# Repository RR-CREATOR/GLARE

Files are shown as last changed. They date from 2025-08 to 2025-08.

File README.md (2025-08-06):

# GLARE  
**Glasses Linked Augmented Reality Engine // By RR-CREATOR (rrop)**



---

## Table of Contents
- [GLARE](#glare)
  - [Intro](#intro)
  - [Why I made this](#why-i-made-this)
  - [PCB](#pcb)
    - [Power](#power)
    - [Main](#main)
    - [Full Board](#full-board)
  - [CAD](#cad)
    - [HUD](#hud)
    - [Camera](#camera)
    - [Frame](#frame)
    - [FULL CAD](#full-cad)
  - [BOM](#bom)

---

## GLARE

### Intro
GLARE is a Glasses Linked Augmented Reality Engine.  
It is basically a glasses attachment.  
It has a custom pcb, which you could place either inside the frame of glasses if you 3d print the frame, or attach it outside.  
It has a custom HUD made using birdbath optics and a 0.39" display, on one side, so you aren't too disconnected with reality, and a lot of the issues caused by cheap optics are resolved through seperate vision.  
It features an esp32-s3-wroom-n16r8 motherboard which, along with a phone(to be added after testing pcb), will get data from 2 mics, a camera, a gyro and gps and give an Augmented Reality experience through the HUD, for assitance in day to day life.

### Why I made this
I made this as I wanted to build something cool yet realistic, something I could carry around with me, and something which I could learn from building.  
I have always wanted my own smart glasses, and what better way to get them than building them yourself?  
I also wanted to get better at pcb design and thus I decided to work on this project and make a custom mainboard.

---

## PCB
It has a custom pcb which serves as its mainboard.

### Power
The pcb has proper power management, and is powered by two batteries in parallel connected to a voltage supervisor.

The pcb also has a micro usb b port which is used to charge the LiPo batteries and is also used for programming the esp 32 module on the board.

It also has a battery gauge, and a power on/off button, along with a low power isolation.

It also has a 5V boost and a 5V to 3.3V LDO to power esp and other peripherals.



### Main
The pcb also has connections for various peripherals, including 2 mics for stereo sound, a camera, a micro oled display, a gps and gyro.

It also has a usb to uart module to programme this esp 32.



### Full Board

**Fully Traced Board:**  


**3D Model of PCB:**  



> Ik the pcb looks lik a cheap cybertruck :3

---

## CAD

### HUD
So the CAD has a representation of the HUD, attached to a small piece, to attach it to the frame.  
(the pieces of the hud will be glued with optically clear glue)



### Camera
It also has a small holder where the camera will go. The holder has an extended piece using which it will be glued to the glasses.



### Frame
The right leg/handle of the glasses frame has a simple design, with its bottom looking like a battery.



The left leg/handle on the other hand is modelled around the shape of the pcb, and is hollow with a cover so that the pcb can be enclosed in it.  
Also, it bottom is hollow, and designed so that a battery can be placed inside it.






### FULL CAD





---

## BOM

<table>
    <tr>
        <td>Category</td>
        <td>Component</td>
        <td>Part Number / Source</td>
        <td>Price (USD)</td>
        <td>Quantity</td>
        <td>Notes</td>
    </tr>
    <tr>
        <td>Core</td>
        <td>ESP32-S3-WROOM-1U-N16R8</td>
        <td>https://lcsc.com/product-detail/WiFi-Modules_ESPRESSIF-ESP32-S3-WROOM-1U-N16R8_C3013946.html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</td>
        <td>5.66</td>
        <td>1</td>
        <td>Core chip with wifi and bt</td>
    </tr>
    <tr>
        <td>Antenna</td>
        <td>Ezurio 001-0014</td>
        <td>https://www.digikey.com/en/products/detail/ezurio/001-0014/4732758</td>
        <td>3.41</td>
        <td>1</td>
        <td>2.4GHz for core</td>
    </tr>
    <tr>
        <td>Mosfet</td>
        <td>PMZ350UPEYL</td>
        <td>https://lcsc.com/product-detail/MOSFETs_Nexperia-PMZ350UPEYL_C478207.html?s_z=n_PMZ350UPEYL</td>
        <td>0.43</td>
        <td>10</td>
        <td>For display power switch</td>
    </tr>
    <tr>
        <td>USB to UART</td>
        <td>CH9102F</td>
        <td>https://lcsc.com/product-detail/USB-Converters_WCH-CH9102F_C2858418.html?s_z=n_CH9102F</td>
        <td>1.33</td>
        <td>1</td>
        <td>For Programming</td>
    </tr>
    <tr>
        <td>I�S Microphone</td>
        <td>SPH0645LM4H-B-8</td>
        <td>https://lcsc.com/product-detail/MEMS-Microphones_Knowles-SPH0645LM4H-B-8_C19190864.html?s_z=n_SPH0645LM4H-B</td>
        <td>8</td>
        <td>2</td>
        <td>MEMS microphone</td>
    </tr>
    <tr>
        <td>Transistors</td>
        <td>2SC4617R</td>
        <td>https://lcsc.com/product-detail/Bipolar-BJT_CBI-2SC4617R_C2836080.html?s_z=n_2SC4617R%2520BR</td>
        <td>0.35</td>
        <td>20</td>
        <td>Programming</td>
    </tr>
    <tr>
        <td>RGB LEDs</td>
        <td>WS2812B 2020</td>
        <td>https://lcsc.com/product-detail/RGB-LEDs-Built-in-IC_Worldsemi-WS2812B-2020_C965555.html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</td>
        <td>0.41</td>
        <td>5</td>
        <td>For visual indication</td>
    </tr>
    <tr>
        <td>Micro USB B</td>
        <td>1050170001</td>
        <td>https://lcsc.com/product-detail/USB-Connectors_MOLEX-1050170001_C136000.html?s_z=n_C136000</td>
        <td>1.67</td>
        <td>1</td>
        <td>Charging LiPo</td>
    </tr>
    <tr>
        <td>Battery Charger</td>
        <td>AP5054HTCER</td>
        <td>https://lcsc.com/product-detail/Battery-Management_Wuxi-Chipown-Micro-electronics-AP5054HTCER_C2843820.html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</td>
        <td>0.15</td>
        <td>1</td>
        <td>Charging LiPo</td>
    </tr>
    <tr>
        <td>Low Voltage Detector</td>
        <td>XC61CC3002MR-G</td>
        <td>https://lcsc.com/product-detail/Supervisor-and-Reset-ICs_TOREX-XC61CC3002MR-G_C2456347.html?s_z=n_XC61CC3002MR</td>
        <td>0.92</td>
        <td>5</td>
        <td>Voltage Supervisor</td>
    </tr>
    <tr>
        <td>Battery Fuel Gauge</td>
        <td>MAX17048</td>
        <td>https://lcsc.com/product-detail/Battery-Management-ICs_Maxim-Integrated-MAX17048G-T10_C2682616.html</td>
        <td>4.16</td>
        <td>1</td>
        <td>Battery Percent</td>
    </tr>
    <tr>
        <td>Voltage Boost</td>
        <td>SY7088</td>
        <td>https://lcsc.com/product-detail/DC-DC-Converters_Silergy-SY7088DGC_C178240.html?s_z=n_SY7088</td>
        <td>1.52</td>
        <td>5</td>
        <td>Convert input to 5V</td>
    </tr>
    <tr>
        <td>LDO</td>
        <td>NCP167BMX330TBG</td>
        <td>https://lcsc.com/product-detail/Voltage-Regulators-Linear-Low-Drop-Out-LDO-Regulators_onsemi-NCP167BMX330TBG_C892227.html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</td>
        <td>0.44</td>
        <td>1</td>
        <td>Convert 5V to 3.3V</td>
    </tr>
    <tr>
        <td>Schottky Diode</td>
        <td>RB160M-30</td>
        <td>https://lcsc.com/product-detail/Schottky-Diodes_High-Diode-RB160M-30_C2937163.html?s_z=n_C2937163</td>
        <td>0.38</td>
        <td>5</td>
        <td>Prevent back current in battery bypass</td>
    </tr>
    <tr>
        <td>Camera Module</td>
        <td>0V5640 160 AF</td>
        <td>https://www.aliexpress.com/item/3256806547258124.html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</td>
        <td>12.75</td>
        <td>1</td>
        <td>5MP autofocus camera</td>
    </tr>
    <tr>
        <td>Gyro + Accelo + Magneto</td>
        <td>ICM-20948</td>
        <td>https://lcsc.com/search?q=ICM-20948&amp;s_z=n_ICM-20948</td>
        <td>4.68</td>
        <td>1</td>
        <td>6-axis IMU</td>
    </tr>
    <tr>
        <td>GPS Module</td>
        <td>L86-M33</td>
        <td>https://www.mouser.in/ProductDetail/Quectel/L86-M33?qs=GedFDFLaBXFvEvNOo6IDYg%3D%3D</td>
        <td>12.82</td>
        <td>1</td>
        <td>Low-power GPS module</td>
    </tr>
    <tr>
        <td>Micro Oled Display</td>
        <td>ET039XGM OLED display + HDMI driver board</td>
        <td>Alibaba (including shipping) </td>
        <td>103</td>
        <td>1</td>
        <td>For HUD</td>
    </tr>
    <tr>
        <td>Mosfet main battery</td>
        <td>YJQD30P02A</td>
        <td>https://lcsc.com/product-detail/MOSFETs_YANGJIE-YJQD30P02A_C919546.html?s_z=n_C919546</td>
        <td>1.36</td>
        <td>5</td>
        <td>Mosfet for high power switching</td>
    </tr>
    <tr>
        <td>Mosfet main battery</td>
        <td>PMZ290UNE2YL</td>
        <td>https://lcsc.com/product-detail/MOSFETs_Nexperia-PMZ290UNE2YL_C478155.html?s_z=n_C478155</td>
        <td>0.53</td>
        <td>10</td>
        <td>Mosfet for high power switching</td>
    </tr>
    <tr>
        <td>Resistor</td>
        <td>10k ohm</td>
        <td>https://lcsc.com/product-detail/Chip-Resistor-Surface-Mount_FOJAN-FRC0402J103-TS_C2906885.html?s_z=n_C2906885</td>
        <td>0.05</td>
        <td>100</td>
        <td>Resistor</td>
    </tr>
    <tr>
        <td>Resistor</td>
        <td>150ohm</td>
        <td>https://lcsc.com/product-detail/Chip-Resistor-Surface-Mount_FOJAN-FRC0402F1500TS_C2909321.html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</td>
        <td>0.05</td>
        <td>100</td>
        <td>Resistor</td>
    </tr>
    <tr>
        <td>Resistor</td>
        <td>100k ohm</td>
        <td>https://lcsc.com/product-detail/Chip-Resistor-Surface-Mount_YAGEO-RC0402JR-07100KL_C106234.html?s_z=n_C106234</td>
        <td>0.06</td>
        <td>100</td>
        <td>Resistor</td>
    </tr>
    <tr>
        <td>Resistor</td>
        <td>2k ohm</td>
        <td>https://lcsc.com/product-detail/Chip-Resistor-Surface-Mount_YAGEO-RC0402FR-072KL_C60488.html?s_z=n_C60488</td>
        <td>0.06</td>
        <td>100</td>
        <td>Resistor</td>
    </tr>
    <tr>
        <td>Resistor</td>
        <td>1M ohm</td>
        <td>https://lcsc.com/product-detail/Chip-Resistor-Surface-Mount_YAGEO-RC0402FR-071ML_C138033.html</td>
        <td>0.07</td>
        <td>100</td>
        <td>Resistor</td>
    </tr>
    <tr>
        <td>Resistor</td>
        <td>470k</td>
        <td>https://lcsc.com/product-detail/Chip-Resistor-Surface-Mount_YAGEO-AC0402JR-07470KL_C227380.html</td>
        <td>0.05</td>
        <td>100</td>
        <td>Resistor</td>
    </tr>
    <tr>
        <td>Resistor/Resettable Fuse</td>
        <td>1A</td>
        <td>https://lcsc.com/product-detail/Resettable-Fuses_JDTfuse-ASMD0805-100_C135331.html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</td>
        <td>0.44</td>
        <td>10</td>
        <td>Charging LiPo</td>
    </tr>
    <tr>
        <td>Resistor</td>
        <td>147k</td>
        <td>https://lcsc.com/product-detail/Chip-Resistor-Surface-Mount_YAGEO-AC0402FR-07147KL_C226785.html</td>
        <td>0.11</td>
        <td>100</td>
        <td>Resistor</td>
    </tr>
    <tr>
        <td>Switch</td>
        <td>SPST Tactile Switch</td>
        <td>https://lcsc.com/product-detail/Tactile-Switches_USAKRO-UK-B0249-SP25Y_C493280.html</td>
        <td>0.85</td>
        <td>5</td>
        <td>User button</td>
    </tr>
    <tr>
        <td>Switch</td>
        <td>Slide Switch</td>
        <td>https://lcsc.com/product-detail/Slide-Switches_Korean-Hroparts-Elec-K3-1270L-F1_C145858.html?s_z=n_C145858</td>
        <td>0.72</td>
        <td>5</td>
        <td>Power on/off</td>
    </tr>
    <tr>
        <td>LiPo battery</td>
        <td>500mAh, 3.7V</td>
        <td>https://robu.in/product/500mah-pcm-protected-micro-li-po-battery-2/</td>
        <td>6</td>
        <td>2</td>
        <td>For power</td>
    </tr>
    <tr>
        <td>Optical Clear Glue</td>
        <td>LOCA</td>
        <td>https://www.aliexpress.com/item/2255800983414695.html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.</td>
        <td>9</td>
        <td>1</td>
        <td>For optics arrangement</td>
    </tr>
    <tr>
        <td>Beam Splitter Cube</td>
        <td>10x10x10mm (including shipping) </td>
        <td>https://www.getuscart.com/beam-splitter-cube-optical-glass-dichroic-prism-ratio-5050-spectrome-sicence-3</td>
        <td></td>
        <td>22</td>
        <td>For optics arrangement</td>
    </tr>
    <tr>
        <td>Combiner</td>
        <td>22x20mm(including shipping)</td>
        <td>https://www.aliexpress.us/item/3256807745776887.html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</td>
        <td>17</td>
        <td>1</td>
        <td>For optics arrangement</td>
    </tr>
    <tr>
        <td>Capacitor</td>
        <td>1uF</td>
        <td>https://lcsc.com/product-detail/Multilayer-Ceramic-Capacitors-MLCC-SMD-SMT_Samsung-Electro-Mechanics-CL05A105KP5NNNC_C14445.html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</td>
        <td>0.17</td>
        <td>100</td>
        <td>Capacitor</td>
    </tr>
    <tr>
        <td>Capacitor</td>
        <td>100nF</td>
        <td>https://lcsc.com/product-detail/Multilayer-Ceramic-Capacitors-MLCC-SMD-SMT_FH-0402B104K160NT_C41851.html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</td>
        <td>0.1</td>
        <td>100</td>
        <td>Capacitor</td>
    </tr>
    <tr>
        <td>Capacitor</td>
        <td>200pF</td>
        <td>https://lcsc.com/product-detail/Multilayer-Ceramic-Capacitors-MLCC-SMD-SMT_YAGEO-CC0402KRX7R9BB201_C277481.html</td>
        <td>0.12</td>
        <td>100</td>
        <td>Capacitor</td>
    </tr>
    <tr>
        <td>Capacitor</td>
        <td>10uF</td>
        <td>https://lcsc.com/product-detail/Multilayer-Ceramic-Capacitors-MLCC-SMD-SMT_Samsung-Electro-Mechanics-CL05A106MQ5NUNC_C15525.html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</td>
        <td>0.06</td>
        <td>10</td>
        <td>Capacitor</td>
    </tr>
    <tr>
        <td>Capacitor</td>
        <td>22uF</td>
        <td>https://lcsc.com/product-detail/Multilayer-Ceramic-Capacitors-MLCC-SMD-SMT_Murata-Electronics-GRM155R60J226ME11D_C415703.html</td>
        <td>0.73</td>
        <td>20</td>
        <td>Capacitor</td>
    </tr>
    <tr>
        <td>LED</td>
        <td>Red</td>
        <td>https://lcsc.com/product-detail/LED-Indication-Discrete_EVERLIGHT-16-213SURC-S530-A3-TR8_C136765.html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</td>
        <td>0.31</td>
        <td>10</td>
        <td>For charging indication</td>
    </tr>
    <tr>
        <td>Inductor</td>
        <td>1.5uH</td>
        <td>https://lcsc.com/product-detail/power-inductors_prod-tech-pspmaa0402-1r5m-anp_C436514.html</td>
        <td>0.74</td>
        <td>5</td>
        <td>Inductor</td>
    </tr>
    <tr>
        <td>PCB</td>
        <td>PCBA</td>
        <td>JLC Estimate (26$ pcb + 16$ shipping, may be more as I havent completed the process)</td>
        <td>40</td>
        <td></td>
        <td></td>
    </tr>
    <tr>
        <td>LiPo battery voltage meter</td>
        <td>QP38</td>
        <td>https://www.amazon.in/Robodo-QP38-Battery-Voltage-Display/dp/B073Q2ZFKF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</td>
        <td>2.68</td>
        <td>1</td>
        <td>for testing lipo voltage</td>
    </tr>
    <tr>
        <td>LiPo battery charger</td>
        <td>Type C</td>
        <td>https://www.amazon.in/Converter-Overcharge-Over-Current-Protection-Module/dp/B0DNCRTZXD</td>
        <td>1.6</td>
        <td>1</td>
        <td>for charging lipo</td>
    </tr>
    <tr>
        <td>1.5m Cable</td>
        <td>USB C to Micro HDMI</td>
        <td>https://www.flipkart.com/microware-hdmi-cable-1-5-m-usb-3-1-type-c/p/itm928cffbd6b34a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</td>
        <td>9</td>
        <td>1</td>
        <td>For display to work, without this display wont work</td>
    </tr>
    <tr>
        <td></td>
        <td></td>
        <td></td>
        <td></td>
        <td></td>
        <td></td>
    </tr>
    <tr>
        <td></td>
        <td></td>
        <td>JUST TO BE ON THE SAFER SIDE, ADDING 20$ for pcba unexpected costs</td>
        <td>20</td>
        <td></td>
        <td></td>
    </tr>
    <tr>
        <td></td>
        <td></td>
        <td></td>
        <td></td>
        <td></td>
        <td></td>
    </tr>
    <tr>
        <td></td>
        <td></td>
        <td></td>
        <td></td>
        <td></td>
        <td></td>
    </tr>
    <tr>
        <td></td>
        <td></td>
        <td></td>
        <td></td>
        <td></td>
        <td></td>
    </tr>
    <tr>
        <td></td>
        <td></td>
        <td>Total Cost</td>
        <td>295.94</td>
        <td></td>
        <td></td>
    </tr>
</table>

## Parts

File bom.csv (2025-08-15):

Category | Component | Part Number / Source | Price (USD) | Quantity | Notes
Core | ESP32-S3-WROOM-1U-N16R8 | https://lcsc.com/product-detail/WiFi-Modules_ESPRESSIF-ESP32-S3-WROOM-1U-N16R8_C3013946.html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 | 5.66 | 1 | Core chip with wifi and bt
Antenna | Ezurio 001-0014 | https://www.digikey.com/en/products/detail/ezurio/001-0014/4732758 | 3.41 | 1 | 2.4GHz for core
Mosfet | PMZ350UPEYL | https://lcsc.com/product-detail/MOSFETs_Nexperia-PMZ350UPEYL_C478207.html?s_z=n_PMZ350UPEYL | 0.43 | 10 | For display power switch
USB to UART | CH9102F | https://lcsc.com/product-detail/USB-Converters_WCH-CH9102F_C2858418.html?s_z=n_CH9102F | 1.33 | 1 | For Programming
I²S Microphone | SPH0645LM4H-B-8 | https://lcsc.com/product-detail/MEMS-Microphones_Knowles-SPH0645LM4H-B-8_C19190864.html?s_z=n_SPH0645LM4H-B | 8 | 2 | MEMS microphone
Transistors | 2SC4617R | https://lcsc.com/product-detail/Bipolar-BJT_CBI-2SC4617R_C2836080.html?s_z=n_2SC4617R%2520BR | 0.35 | 20 | Programming
RGB LEDs | WS2812B 2020 | https://lcsc.com/product-detail/RGB-LEDs-Built-in-IC_Worldsemi-WS2812B-2020_C965555.html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 | 0.41 | 5 | For visual indication
Micro USB B | 1050170001 | https://lcsc.com/product-detail/USB-Connectors_MOLEX-1050170001_C136000.html?s_z=n_C136000 | 1.67 | 1 | Charging LiPo
Battery Charger | AP5054HTCER | https://lcsc.com/product-detail/Battery-Management_Wuxi-Chipown-Micro-electronics-AP5054HTCER_C2843820.html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 | 0.15 | 1 | Charging LiPo
Low Voltage Detector | XC61CC3002MR-G | https://lcsc.com/product-detail/Supervisor-and-Reset-ICs_TOREX-XC61CC3002MR-G_C2456347.html?s_z=n_XC61CC3002MR | 0.92 | 5 | Voltage Supervisor
Battery Fuel Gauge | MAX17048 | https://lcsc.com/product-detail/Battery-Management-ICs_Maxim-Integrated-MAX17048G-T10_C2682616.html | 4.16 | 1 | Battery Percent
Voltage Boost | SY7088 | https://lcsc.com/product-detail/DC-DC-Converters_Silergy-SY7088DGC_C178240.html?s_z=n_SY7088 | 1.52 | 5 | Convert input to 5V
LDO | NCP167BMX330TBG | https://lcsc.com/product-detail/Voltage-Regulators-Linear-Low-Drop-Out-LDO-Regulators_onsemi-NCP167BMX330TBG_C892227.html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 | 0.44 | 1 | Convert 5V to 3.3V
Schottky Diode | RB160M-30 | https://lcsc.com/product-detail/Schottky-Diodes_High-Diode-RB160M-30_C2937163.html?s_z=n_C2937163 | 0.38 | 5 | Prevent back current in battery bypass
Camera Module | 0V5640 160 AF | https://www.aliexpress.com/item/3256806547258124.html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 | 12.75 | 1 | 5MP autofocus camera
Gyro + Accelo + Magneto | ICM-20948 | https://lcsc.com/search?q=ICM-20948&s_z=n_ICM-20948 | 4.68 | 1 | 6-axis IMU
GPS Module | L86-M33 | https://www.mouser.in/ProductDetail/Quectel/L86-M33?qs=GedFDFLaBXFvEvNOo6IDYg%3D%3D | 12.82 | 1 | Low-power GPS module
Micro Oled Display | ET039XGM OLED display + HDMI driver board | Alibaba (including shipping) | 110 | 1 | For HUD
Mosfet main battery | YJQD30P02A | https://lcsc.com/product-detail/MOSFETs_YANGJIE-YJQD30P02A_C919546.html?s_z=n_C919546 | 1.36 | 5 | Mosfet for high power switching
Mosfet main battery | PMZ290UNE2YL | https://lcsc.com/product-detail/MOSFETs_Nexperia-PMZ290UNE2YL_C478155.html?s_z=n_C478155 | 0.53 | 10 | Mosfet for high power switching
Resistor | 10k ohm | https://lcsc.com/product-detail/Chip-Resistor-Surface-Mount_FOJAN-FRC0402J103-TS_C2906885.html?s_z=n_C2906885 | 0.05 | 100 | Resistor
Resistor | 150ohm | https://lcsc.com/product-detail/Chip-Resistor-Surface-Mount_FOJAN-FRC0402F1500TS_C2909321.html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 | 0.05 | 100 | Resistor
Resistor | 100k ohm | https://lcsc.com/product-detail/Chip-Resistor-Surface-Mount_YAGEO-RC0402JR-07100KL_C106234.html?s_z=n_C106234 | 0.06 | 100 | Resistor
Resistor | 2k ohm | https://lcsc.com/product-detail/Chip-Resistor-Surface-Mount_YAGEO-RC0402FR-072KL_C60488.html?s_z=n_C60488 | 0.06 | 100 | Resistor
Resistor | 1M ohm | https://lcsc.com/product-detail/Chip-Resistor-Surface-Mount_YAGEO-RC0402FR-071ML_C138033.html | 0.07 | 100 | Resistor
Resistor | 470k | https://lcsc.com/product-detail/Chip-Resistor-Surface-Mount_YAGEO-AC0402JR-07470KL_C227380.html | 0.05 | 100 | Resistor
Resistor/Resettable Fuse | 1A | https://lcsc.com/product-detail/Resettable-Fuses_JDTfuse-ASMD0805-100_C135331.html | 0.44 | 10 | Charging LiPo
Resistor | 147k | https://lcsc.com/product-detail/Chip-Resistor-Surface-Mount_YAGEO-AC0402FR-07147KL_C226785.html | 0.11 | 100 | Resistor
Switch | SPST Tactile Switch | https://lcsc.com/product-detail/Tactile-Switches_USAKRO-UK-B0249-SP25Y_C493280.html | 0.85 | 5 | User button
Switch | Slide Switch | https://lcsc.com/product-detail/Slide-Switches_Korean-Hroparts-Elec-K3-1270L-F1_C145858.html?s_z=n_C145858 | 0.72 | 5 | Power on/off
LiPo battery | 500mAh, 3.7V | https://robu.in/product/500mah-pcm-protected-micro-li-po-battery-2/ | 6 | 2 | For power
Optical Clear Glue | LOCA | https://www.aliexpress.com/item/2255800983414695.html?mp=1 | 9 | 1 | For optics arrangement
Beam Splitter Cube | 10x10x10mm (including shipping) | https://www.getuscart.com/beam-splitter-cube-optical-glass-dichroic-prism-ratio-5050-spectrome-sicence-3 | 22 | 1 | For optics arrangement
Combiner | 22x20mm (including shipping) | https://www.aliexpress.us/item/3256807745776887.html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 | 17 | 1 | For optics arrangement
Capacitor | 1uF | https://lcsc.com/product-detail/Multilayer-Ceramic-Capacitors-MLCC-SMD-SMT_Samsung-Electro-Mechanics-CL05A105KP5NNNC_C14445.html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 | 0.17 | 100 | Capacitor
Capacitor | 100nF | https://lcsc.com/product-detail/Multilayer-Ceramic-Capacitors-MLCC-SMD-SMT_FH-0402B104K160NT_C41851.html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 | 0.1 | 100 | Capacitor
Capacitor | 200pF | https://lcsc.com/product-detail/Multilayer-Ceramic-Capacitors-MLCC-SMD-SMT_YAGEO-CC0402KRX7R9BB201_C277481.html | 0.12 | 100 | Capacitor
Capacitor | 10uF | https://lcsc.com/product-detail/Multilayer-Ceramic-Capacitors-MLCC-SMD-SMT_Samsung-Electro-Mechanics-CL05A106MQ5NUNC_C15525.html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 | 0.06 | 10 | Capacitor
Capacitor | 22uF | https://lcsc.com/product-detail/Multilayer-Ceramic-Capacitors-MLCC-SMD-SMT_Murata-Electronics-GRM155R60J226ME11D_C415703.html | 0.73 | 20 | Capacitor
LED | Red | https://lcsc.com/product-detail/LED-Indication-Discrete_EVERLIGHT-16-213SURC-S530-A3-TR8_C136765.html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 | 0.31 | 10 | For charging indication
Inductor | 1.5uH | https://lcsc.com/product-detail/power-inductors_prod-tech-pspmaa0402-1r5m-anp_C436514.html | 0.74 | 5 | Inductor
PCB | PCBA | JLC Estimate (26$ pcb + 16$ shipping, may be more as I havent completed the process) | 40
LiPo battery voltage meter | QP38 | https://www.amazon.in/Robodo-QP38-Battery-Voltage-Display/dp/B073Q2ZFKF | 2.68 | 1 | for testing lipo voltage
LiPo battery charger | Type C | https://www.amazon.in/Converter-Overcharge-Over-Current-Protection-Module/dp/B0DNCRTZXD | 1.6 | 1 | for charging lipo
1.5m Cable | USB C to Micro HDMI | https://www.flipkart.com/microware-hdmi-cable-1-5-m-usb-3-1-type-c/p/itm928cffbd6b34a?pid=ACCF8DCB4FU6Z7SN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 | 9 | 1 | For display to work, without this display wont work
 |  | JUST TO BE ON THE SAFER SIDE, ADDING 20$ for pcba unexpected costs | 20
 |  | Total Cost | 302.94

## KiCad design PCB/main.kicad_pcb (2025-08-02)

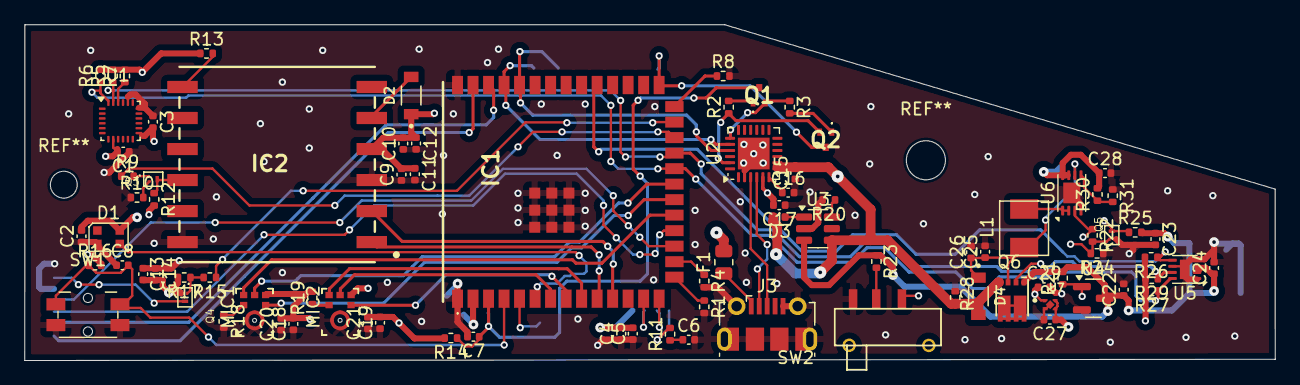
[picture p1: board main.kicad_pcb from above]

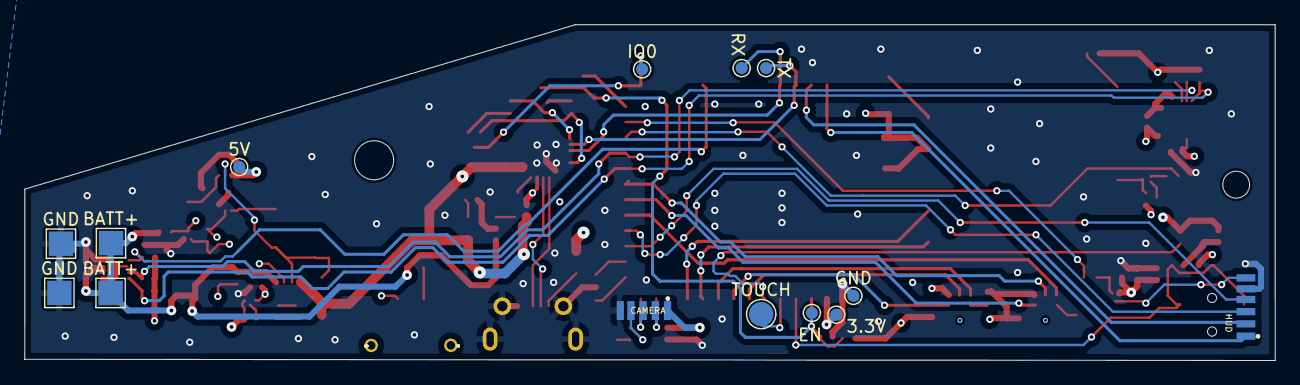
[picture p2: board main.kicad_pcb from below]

Board: 4 copper layers, 102.4 x 27.5 mm, 100 parts (14 on the bottom side), 64 nets.

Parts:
3.3V: 3V3; TestPoint_Pad_D1.0mm
5V: 5V; TestPoint_Pad_D1.0mm
BATT+: BATT1+; TestPoint_Pad_2.0x2.0mm
BATT+#2: BATT2+; TestPoint_Pad_2.0x2.0mm
C1, C3, C4, C6, C8, C9, C10, C14, C16, C17, C20, C21, C22, C24, C27: 100nF; C_0402_1005Metric
C2, C5, C7, C11, C12, C13, C15, C25, C29: 1uF; C_0402_1005Metric
C18, C19: 200pF; C_0402_1005Metric
C23, C26, C28: 22uF; C_0402_1005Metric
CAMERA: Camera; Solder-5P-Connector
D1: WS2812B-2020; LED_WS2812B-2020_PLCC4_2.0x2.0mm
D2, D4: RB160M-30; DIO_RB160M-30
D3: Red; D_0402_1005Metric
EN: EN; TestPoint_Pad_D1.0mm
F1: 1A; R_0805_2012Metric
GND: BATT1-; TestPoint_Pad_2.0x2.0mm
GND#2: GND; TestPoint_Pad_D1.0mm
GND#3: BATT2-; TestPoint_Pad_2.0x2.0mm
HUD: HUD; Solder-6P-Connector
IC1: ESP32-S3-WROOM-1U-N16R8; ESP32S3WROOM1UN16R8
IC2: L86-M33; L80-M39
IO0: IO0; TestPoint_Pad_D1.0mm
J3: USB_B_Micro; USB_Micro-B_Molex-105017-0001
L1: 1.5uH; 1.5uH_YXMAA0402-1R5M-ANP
MIC1, MIC2: SPH0645LM4H-B; SPH0645LM4H-B-2
Q1, Q2: 2SC4617-R-TP; 2SC4617RTP
Q3, Q4: PMZ350UPEYL; DFN100X60X40-3N
Q5: PMZ290UNE2YL; DFN100X60X40-3N
Q6: YJQD30P02A; EMF20B02V
R1, R2, R3, R4, R7, R8, R12, R13, R14, R15, R16, R18, R19, R23, R26: 10k; R_0402_1005Metric
R5, R6, R27, R29: 4.7k; R_0402_1005Metric
R9, R10: 1k; R_0402_1005Metric
R11, R25, R28: 1M; R_0402_1005Metric
R17, R21, R24: 100k; R_0402_1005Metric
R20: 2.1k; R_0402_1005Metric
R22: 150; R_0402_1005Metric
R30: 470k; R_0402_1005Metric
R31: 147k; R_0402_1005Metric
RX: RX; TestPoint_Pad_D1.0mm
SW1: SW_SPST; SMD_Switch_Panasonic_EVQPUL_EVQPUC_6.3x6.7
SW2: Power; SW_SMD_SPDT_Slide_9x6.9-hole
TOUCH: Touch Pad; TestPoint_Pad_D2.0mm
TX: TX; TestPoint_Pad_D1.0mm
U1: ICM-20948; InvenSense_QFN-24_3x3mm_P0.4mm
U2: CH9102F; QFN-24-1EP_4x4mm_P0.5mm_EP2.6x2.6mm
U3: AP5054HTC; SOT-23-6
U4: XC61CC3002MR; SOT-23
U5: MAX17048; DFN-8-1EP_2x2mm_P0.5mm_EP0.8x1.6mm
U6: SY7088; DFN-8-1EP_3x2mm_P0.5mm_EP1.7x1.4mm
U7: NCP167BMX330TBG; VREG_NCP167BMX330TBG

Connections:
+3.3V: 3.3V.1, C1.2, C3.2, C9.2, C10.2, C11.1, C12.1, C17.2, C18.2, C19.2, C20.2, C21.2, C29.1, D2.C, IC1.2 (3V3), IC2.4 (VCC), MIC1.5 (VDD), MIC2.5 (VDD), R5.2, R6.2, R7.2, R12.2, R13.1, R14.2, R16.2, R19.2, R26.2, R27.2, R29.2, U1.8 (VDDIO), U1.13 (VDD), U2.5 (VIO), U7.1 (OUT)
+5V: 5V.1, C2.2, C4.2, C5.2, C13.2, C14.2, C27.1, C28.1, CAMERA.1, D1.4 (VDD), Q4.2 (S), R17.2, R30.2, U6.7 (OUT), U6.8 (OUT), U7.3 (EN), U7.4 (IN)
ALRT: IC1.31 (IO38), R26.1, U5.5 (ALRT)
BATT+: BATT+.1, BATT+#2.1, C22.1, C23.1, C24.1, Q6.1 (S2), R21.2, R23.1, R25.2, U3.3 (BAT), U4.3 (VIN), U5.2 (CELL), U5.3 (Vdd)
BRT+: HUD.4, IC1.17 (IO9)
BRT-: HUD.3, IC1.18 (IO10)
D+: CAMERA.3, IC1.14 (IO20)
D-: CAMERA.2, IC1.13 (IO19)
DTR: Q2.2 (E), R2.1, U2.23 (~DTR)
EN: C7.1, EN.1, IC1.3 (EN), Q1.3 (C), R14.1
GND: C1.1, C2.1, C3.1, C4.1, C5.1, C6.2, C7.2, C8.1, C9.1, C10.1, C11.2, C12.2, C13.1, C14.1, C15.1, C16.2, C17.1, C18.1, C19.1, C20.1, C21.1, C22.2, C23.2, C24.2, C25.2, C26.2, C27.2, C28.2, C29.2, CAMERA.5, D1.2 (VSS), GND.1, GND#2.1, GND#3.1, HUD.5, IC1.1 (GND_1), IC1.40 (GND_2), IC1.41 (GND_3), IC1.42 (GND_4), IC1.43 (GND_5), IC1.44 (GND_6), IC1.45 (GND_7), IC1.46 (GND_8), IC1.47 (GND_9), IC1.48 (GND_10), IC1.49 (GND_11), IC2.3 (GND_1), IC2.12 (GND_2), J3.5 (GND), J3.6 (Shield), MIC1.3 (GND), MIC2.3 (GND), Q5.2 (S), R1.2, R4.2, R8.2, R10.1, R18.2, R20.2, R24.1, R28.1, R31.1, SW1.2 (B), SW2.1 (A), U1.18 (GND), U1.20 (GND), U2.2 (GND), U2.25 (GND), U3.2 (GND), U4.2 (GND/VSS), U5.1 (CTG), U5.4 (GND), U5.6 (QSTRT), U5.9 (EP), U6.4 (GND), U6.9 (Pad), U7.2 (GND), U7.5 (EPAD)
GRX: IC1.10 (IO17), IC2.1 (RXD1)
GTX: IC1.11 (IO18), IC2.2 (TXD1)
HUD+: HUD.6, Q4.3 (D)
HUD_EN: IC1.25 (IO48), R15.1
I2SCLK1: IC1.20 (IO12), MIC1.4 (BCLK)
I2SCLK2: IC1.8 (IO15), MIC2.4 (BCLK)
I2SDATA1: IC1.21 (IO13), MIC1.6 (DATA_OUT)
I2SDATA2: IC1.7 (IO7), MIC2.6 (DATA_OUT)
I2SWS1: IC1.19 (IO11), MIC1.1 (WS)
I2SWS2: IC1.9 (IO16), MIC2.1 (WS)
IO0: IC1.27 (IO0), IO0.1, Q2.3 (C)
unnamed: C6.1, R11.1
unnamed: D3.1 (K), U3.1 (~CHRG)
unnamed: IC1.15 (IO3), R1.1
unnamed: IC1.26 (IO45), R8.1
unnamed: IC1.16 (IO46), R4.1
unnamed: IC2.7 (FORCE_ON), R13.2
unnamed: IC2.10 (RESET), Q3.3 (D), R12.1
unnamed: D2.A, IC2.5 (V_BCKP)
unnamed: CAMERA.4, R11.2
unnamed: F1.1, J3.1 (VBUS)
unnamed: L1.2, U6.1 (LX), U6.2 (LX)
unnamed: MIC1.2 (SELECT), R18.1
unnamed: MIC2.2 (SELECT), R19.1
unnamed: Q1.1 (B), R2.2
unnamed: Q2.1 (B), R3.2
unnamed: Q3.1 (G), R9.2
unnamed: Q3.2 (S), R10.2
unnamed: Q4.1 (G), R15.2, R17.1
unnamed: Q5.3 (D), Q6.2 (G2), R25.1
unnamed: Q5.1 (G), R22.2, R24.2, SW2.2 (B)
unnamed: Q6.5 (D2), Q6.6 (D2), Q6.7 (D2), Q6.8 (D2)
unnamed: C25.1, C26.1, D4.C, L1.1, Q6.3 (S2), U6.6 (IN)
unnamed: R23.2, SW2.3 (C)
unnamed: R7.1, U1.22 (~CS)
unnamed: C16.1, U2.6 (V3)
unnamed: R20.1, U3.6 (PROG)
unnamed: R30.1, R31.2, U6.5 (FB)
PSEN: R21.1, R22.1, U4.1 (VOUT), U6.3 (EN)
RESETGPS: IC1.24 (IO47), R9.1
RGB: D1.3 (DIN), IC1.6 (IO6)
RTS: Q1.2 (E), R3.1, U2.19 (~RTS)
RX_ESP: IC1.36 (RXD0), RX.1, U2.21 (TXD)
RX_esp_hud: HUD.2, IC1.38 (IO2)
SCL: IC1.23 (IO21), R5.1, R29.1, U1.23 (SCL/SCLK), U5.7 (SCL)
SDA: IC1.22 (IO14), R6.1, R27.1, U1.24 (SDA/SDI), U5.8 (SDA)
Switch: C8.2, IC1.4 (IO4), R16.1, SW1.1 (A)
TX_ESP: IC1.37 (TXD0), TX.1, U2.20 (RXD)
TX_esp_hud: HUD.1, IC1.39 (IO1)
Touch: IC1.5 (IO5), TOUCH.1
USB+: J3.3 (D+), U2.3 (UD+)
USB-: J3.2 (D-), U2.4 (UD-)
VBUS: C15.2, D3.2 (A), D4.A, F1.2, Q6.4 (G2), R28.2, U2.7 (VDD5), U2.8 (VBUS), U3.4 (VCC)

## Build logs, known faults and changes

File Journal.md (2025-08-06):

---
Title: "GLARE"
Author: "rrop"
Description: "AR Glasses for everyday assistance"
Created On: "2025-07-25"
---

*Total Time Spent: 62h*

# July 25th: Optics Research
\
Ok so I googles AR glasses optics mechanisms and figured out that three main optics systems are used.\
smtg known as waveguide, smtg called birdbath and then the good old prism(also called wavesplitter optics by some websites).\
So basically for waveguide the have a projector like micro oled display which shoots light and the the guide it through inbuilt micro optics in the lens to get the hud. Buuuutttt :\
  1. super expensive
  2. Not hackable/Diy able
  3. No clue wehere i could even get it\
So waveguide is a no go. (ps its used in even realities G1)\
\
\
\
Then there is wavesplitter. So basically light from a micro oled is first collimated by a lens, and then passed through a special prism called beamsplitter, which makes it so that half the light entering the eye is from the display and other half from outside world.\
It works, and is pretty small, but the issue is it has a lot of imperfections and causes double images.\
I did an optics sim on phydemo for this



This is pretty simply optics so ill use either this or birdbath.

An example of birdbath is google glass explorer. It basically involves the same thing as the wabvesplitter, just tat light exiting prism is then focused by a semi transparent mirror onto the eye, along with a bit of light from outside world.\
This system reduces the imperfections by a lot, but is pretty bulky and tougher to get right.

Screenshot 2025-05-23 at 10 08 52 PM

SOOOO rn im super confused wut to do, i guess ill (as in make gpt ...) do some calc and figure out wut i want.\
OKKKKK, so i did some mth (:P) and figured out that i can try for a birdbath and if worst case it doesnt work i can just reposition the beam splitter prism and the system will work as wavesplitter optics. Yippe
So ill try to do birdbath ig.

**Session time spent: 5h**

# July 26th: More Research

So now tat I decided on birdbath, I had to find decide on the display I was gonna use. \
So, I did some searching about micro oleds and found a good one for a good price on alibaba.\
It also came with the driver board so that was a plus.\
Its the ET039XGM Micro OLED, and its 0.39".

SO now finally I could do some optics calcs.\
Before that, I also made a rough simulation of birdbath on phydemo.



here the outside light wiuld enter through the spherical mirror, which is supposed to be semi transparent [I cant show tht on phydemo :( ]\
\
So by estimation, using oled size, a 10x10x10mm beam splitter cube with a 45degree prism would suffice. \
Using this, and thin lens equation, i figured out tat the focal length of collimating lens shuld be 13-14mm, as thats distance bw display and prism. \
and then I can place the combiner just after the  prism. \
I also learned tat basically the combiner is almost flat, its slightly curevd. \
Its purpose is just to redirect light and include outside light. \
and as combiner is just after prism, its size has to be bigger than prism so it can effectively redirect light directed towards it. \
Sooo, ill be getting one of i guess a 20x20 size. \
I googles and yippe found a 22x20mm one. 

So basically i finally finished my optics, and will start my pcb tmrw.\
\
**Session time spent: 4h**

# July 27th: PCB Time, or is it?
\
Soo for the pcb, I decided that I would be making an FGPA board of sorts.\
So like basically a full on computer that could linux and that would control everything else.\
I decided I wanted a camera, google a bit and found that I liked the OV5640 AF. \
I also wanted a mic, gyro, gps and wifi nd bt capabilities. So I went on googling the components I could use.\
I decided upon the RK3566. Its one of the newer rockchip socs. Also i wanted it to be small, so instead of using an SOM I decided to use the SOC and choose the other stuf myself.\
For the RAM is choose IM8G32L4JCBG-046I which is a 1GB LPDDR4X. For flash, 128Mb of SPI NOR flash. Also a chip with 8gb emmc and for pmic an rk817-5.\
\
BOM img:
\

\
This research took lik 5 hrs, as I had to find the libraries, datasheets and kicad footprints and symbols of each as well.\
\
BUTT, As soon as I started on the schematic I realized smtg. THIS SHIT WAS WAYYYY TO COMPLEX. IT would take atleast 2 weeks and i dint hv tat much time :(\
SOO I scrapped this idea altogether and spent like another hour thinkin wut to do :/\
\
SOOOO..... I GIT A GOOD IDEA.\
Basically, ill use an esp 32 module as the core chip, and the peripherals will send data to it and stuf. Then itll communicate the data to a phone through its BT or wifi.\
The phone will do all the processing.\
ALSOOOOO, the hud driver board is HDMI. So i can directly control it through the phone through a usb c to micro hdmi cable. Another plus\
\
SO i made a rough plan of wut I would need.
1. esp
2. usb to uart to progrma it
3. 2 lipo bats for power (3.7v 500mah)
4. a voltage regulator
5. ldo
6. voltage boost
7. smtg to measure battery %
8. peripherals (stuf lik cam, gps, switches etc)
9. smtg to charge lipo

ANNDDD I DID A SHIT TON of research and finally decided upon a good esp32 module ill use as core.\
Its the ESP32-S3-WROOM-1U-N16R8\
It has 16GB flash, 8GB PSRAM wifi bt and usb support for my camera\
\
Ill do the rest of the bom tmrw\
\
**Session time spent: 7h**

# July 28th: BOM + Schematic
\
Soo for the pcb, I wont get into the details. Like there isnt much to discuss particularly.\
I just spent a shit ton of time (5 hrs) looking at datasheets, chat gpting and googling a lot of shit and finally finished the BOM.\ 
(it took a lot of time as I was also simultaneously finding the footprints and symbols of the parts I was gonna use)\
\

\
PS.. This diesbt have the otpics and lipo. Ill add those later.\
\
ANYWS. FINALLY TIME TO START WITH THE SCHEMATIC\
so i started with the power management part.\
\
So i was gonna have a micro usb b port which would be both for programming and charging the lipos.\
\

\
This was the schematic.\
So the usb prot d+ and d- ill later connect to d+ and d- of usb to uart.\
the fuse protect the charger from overcurrent.\
\
The prog sets charge current. For ap5054, its equal to 1200/resistance bw prog and gnd. as im using 2 lipos in parallel, ill keep it as 2k ohm so that the batteries charge at 600mAh.\
i.e. 0.6C which is good.\
\
Now time for the voltage supervisor to prevernt the lipos from burning out. : p\
\

\
here the vout will be connected to psen of the 5v boost to enable power saving.\
\
Now time for power on/off and the 5v boost.\
\

\
THIS SCHEMATIC TOOK WAYYYYYYY TOOOO LONG.\
\
now for the easy part. the battery gauge and the ldo to convert 5v to 3.3v(esp and lots of components have 3.3v logic)\
\

\
this was pretty easy.\
\
FINALLLYY, AFTER ALMOST THE ENTIRE DAY... THE POWER PART OF THE SCHEMATIC IS DONE\
\

\
**Session time spent: 13h**

# July 29th: Schematic 2
\
Time for the components part of the schematic\
\
USB TO UART: DONE\
\

\
Now i addes some transistors to the esp reset button and for the boot mode gpio. Ive connected them to the usb to uart dtr and rts.\
\

\
DONE\
\
Now the gyro:\
\

\
now the gps:\
\

\
Right I also added a gpio to control the state of the reset pin, so incase the gps misfires or gives wrong data, i can reset it through code.
\
Now the mics:\
\

\
Now the hud: for the hud also i added a gpio to control wether its on or off.\
\

\
The camera:\
\

\
the led:\
\

\
right i just remembered. I might have forgotten to mention this before, but i added a red led to the charging path, so that when the lipos are charging, you can visually tell\
\
and a touch reset user switch:\
\

\
and finally, after going through the datasheets a million times:\
the esp:\
\

\
There isnt much to say or explain about this, it was just adding and connecting the parts. But it still took me the entire day basically\
The schematic is officially done, and Ill start routing\
\
**Session time spent: 12h**

# July 30th: Routing
\
There isn't much to say abt this part. \
I just imported the parts from the schematic and spent a shit ton of time routing amd positioning everything.\
I started with the usb, i2s and i2c. Then the serial and uart, then the gpio and then power.\
The pwoer traces were pretty thick and others were default size pretty much.\
Its a 4 layer pcb so I can make it small and stuf.\
\
So basically I finished routing almost everything except the +5v, vbus and stuf. Will do tat tmrw\
\
**Session time spent: 12h**

# July 31th: Finishing Routing, CAD and Firmware
\
Ok so I spent lik 2 hrs and finished the routing.\
\

\
\
Now time for cad
\
For this I spent like 15 mins and found a step model of glasses.\ 
I imported that into my cad.\
Then i deleted their arms, extended two rectangles and modeled the base part slightly angles downwards and in the shape of battery so they can act as battery housing.\
I then modelled the left arm to be hollow and in such a way that my pcb sits firmly withing it, by creating a sketch around the pcb.\
I also modeled the hud after this, and a mount for the camera, with an extension where i can super glue it to the glasses.\
\
Overall, this entire modelling took me abt 4 hrs.\
\



Now time for the firmware.\
For the firmware, I decided to use platformio, so tat later on interfacing would be easier and testing and dev would also be pretty easy.\
\
SOOO, I created projected and luckily found a board verryy close to mine. The only diff was tat mine has 16Mb flash while this board has 8Mb.\
But i dont think while programming it would make much difference.\
\
Anyws, I organised stuf into folders. Figured out how platformio works a little more (2nd time using it)\
and wrote up basic code for all the components.\
\
So i googled and figured out that its better to add stuf in a folder called include so tat those files dont get called multiple times\
(I hv no clue wut this means, just tat multiple people online suggested it so ill do it : P )\
\
Anyws, finalllYY FIRMWARE DONE AND EVERYTHING DONE.... FOR now.. YIPPEEEEE : )\
\
**Session time spent: 10h**

**Total Time Spent: 62h**

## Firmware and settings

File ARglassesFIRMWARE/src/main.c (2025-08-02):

#include "utils/brightness.h"
#include "utils/microphones.h"
#include "utils/gps.h"
#include "utils/i2c_devices.h"
#include "display/hud.h"
#include "driver/gpio.h"
#include "driver/uart.h"

#define HUD_ENABLE_GPIO 48
#define HUD_UART_TX 1
#define HUD_UART_RX 2

void app_main(void) {
    gpio_reset_pin(HUD_ENABLE_GPIO);
    gpio_set_direction(HUD_ENABLE_GPIO, GPIO_MODE_OUTPUT);
    gpio_set_level(HUD_ENABLE_GPIO, 1);

    brightness_init();
    microphones_init();
    gps_init();
    i2c_devices_init();
}

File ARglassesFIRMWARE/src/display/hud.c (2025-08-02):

#include "display/hud.h"
#include "driver/uart.h"
#include "driver/gpio.h"

#define HUD_ENABLE_GPIO 48
#define HUD_UART_TX 1
#define HUD_UART_RX 2

void hud_init(void) {
    gpio_reset_pin(HUD_ENABLE_GPIO);
    gpio_set_direction(HUD_ENABLE_GPIO, GPIO_MODE_OUTPUT);
    gpio_set_level(HUD_ENABLE_GPIO, 1);

    uart_config_t uart_config = {
        .baud_rate = 115200,
        .data_bits = UART_DATA_8_BITS,
        .parity    = UART_PARITY_DISABLE,
        .stop_bits = UART_STOP_BITS_1,
        .flow_ctrl = UART_HW_FLOWCTRL_DISABLE
    };
    uart_driver_install(UART_NUM_2, 1024, 0, 0, NULL, 0);
    uart_param_config(UART_NUM_2, &uart_config);
    uart_set_pin(UART_NUM_2, HUD_UART_TX, HUD_UART_RX, UART_PIN_NO_CHANGE, UART_PIN_NO_CHANGE);
}

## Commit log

2025-08-02 Rename Frame with electronics and hud v2.step to CAD/Frame with electronics and hud v2.step
    [Frame with electronics and hud v2.step]
2026-06-29 Complete ESP32-S3 firmware with live transcription
    Fix I2S mic init (wrong clock, wrong slot width for SPH0645, never enabled)
    Add microphones_read() for actual PCM capture
    Add WiFi + WebSocket streaming pipeline (glare_net.c)
    Add HUD text output (hud_show/hud_show_n over UART)
    Wire app_main with NVS init and full boot sequence
    Add glare_config.h for WiFi/WS/audio config
    Add reference transcription backend (faster-whisper)
    Add board JSON, sdkconfig.defaults (16MB flash + OPI PSRAM)
    Add huge_app.csv partition table
    Vendor esp_websocket_client + led_strip as local components
    Bump platform to espressif32@6.5.0 (ESP-IDF 5.1)
    Build verified: SUCCESS (917KB flash, 37KB RAM)
